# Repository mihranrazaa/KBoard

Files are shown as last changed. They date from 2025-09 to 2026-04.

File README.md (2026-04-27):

# KBoard

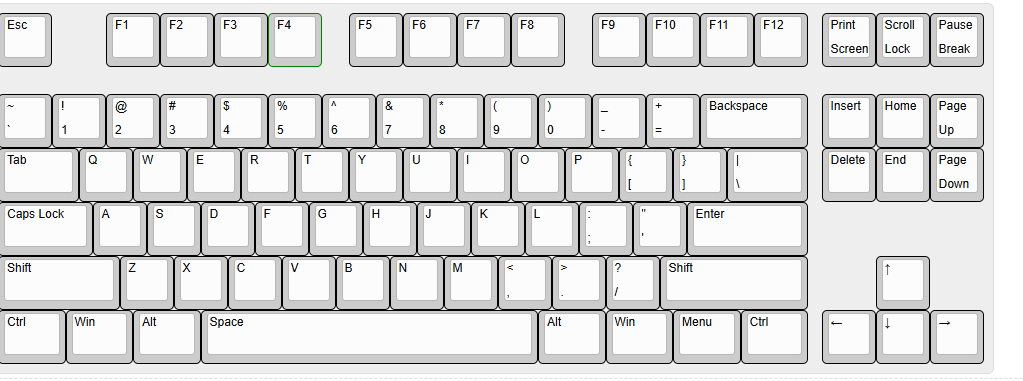
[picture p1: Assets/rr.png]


## Overview
a 75%% keyboard design, it is based on RP2040 plus with a type C port which came in-built with the MCU, there total of 87 MX switches with 5 Stabilizers. A complete keyboard :).

## Bit in depth info
The keyboard is designed to be sleek and plane it has RP2040 plus as the MCU and Cherry MX Brown Switches for the keys which are used for versatile purposes (that's what i saw at least). The main firmware is KMK based and the Firmware has already been released, you can find that in the Firmware and Production folder, I hate using different cables so having type c inbuilt in the RP2040 plus is a win-win.

---

## Files to build 

### PCB 

The files for the PCB and Schematics are available in the Kicad folder and gerber files are added in the Production folder..

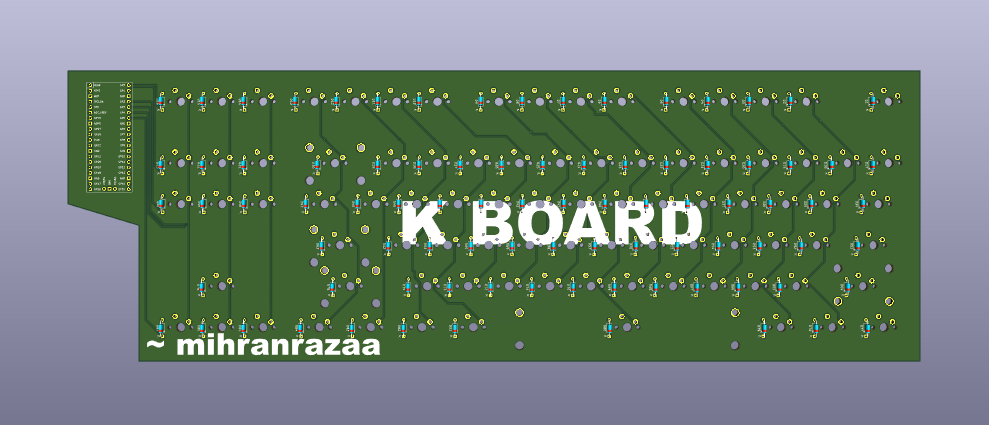
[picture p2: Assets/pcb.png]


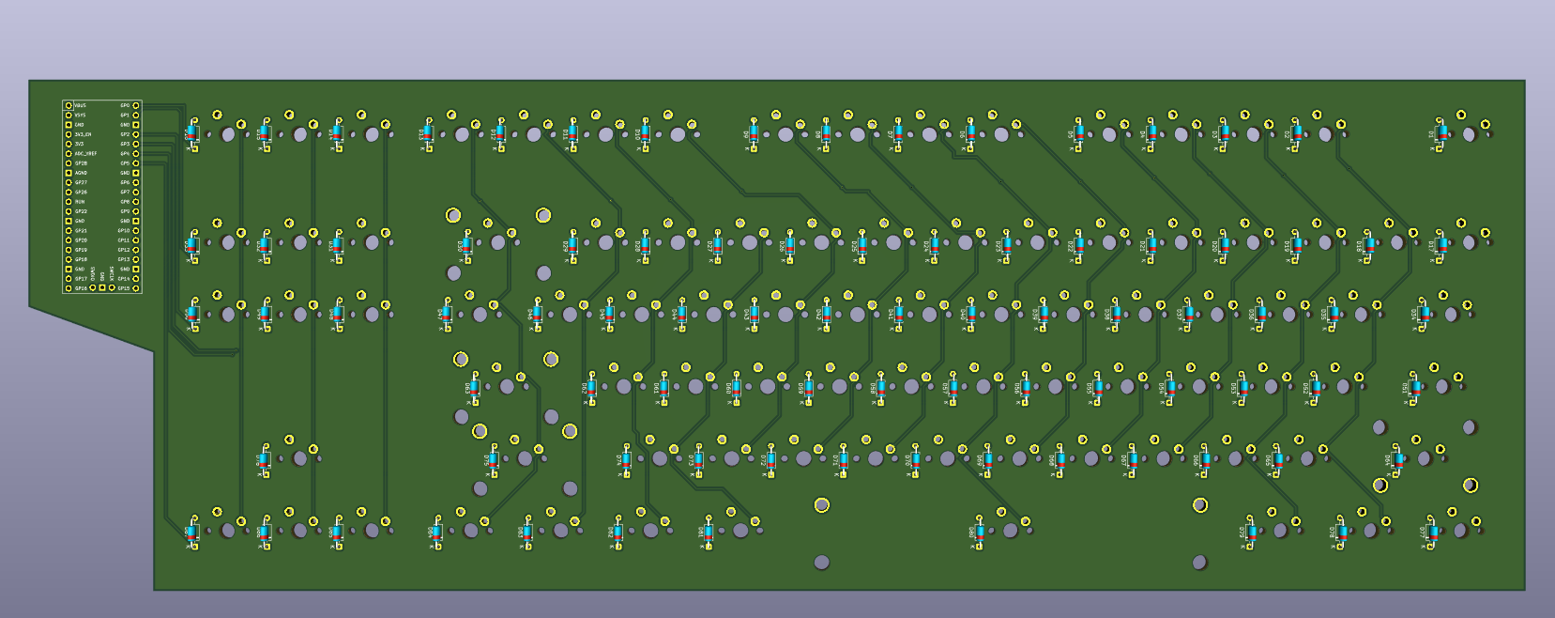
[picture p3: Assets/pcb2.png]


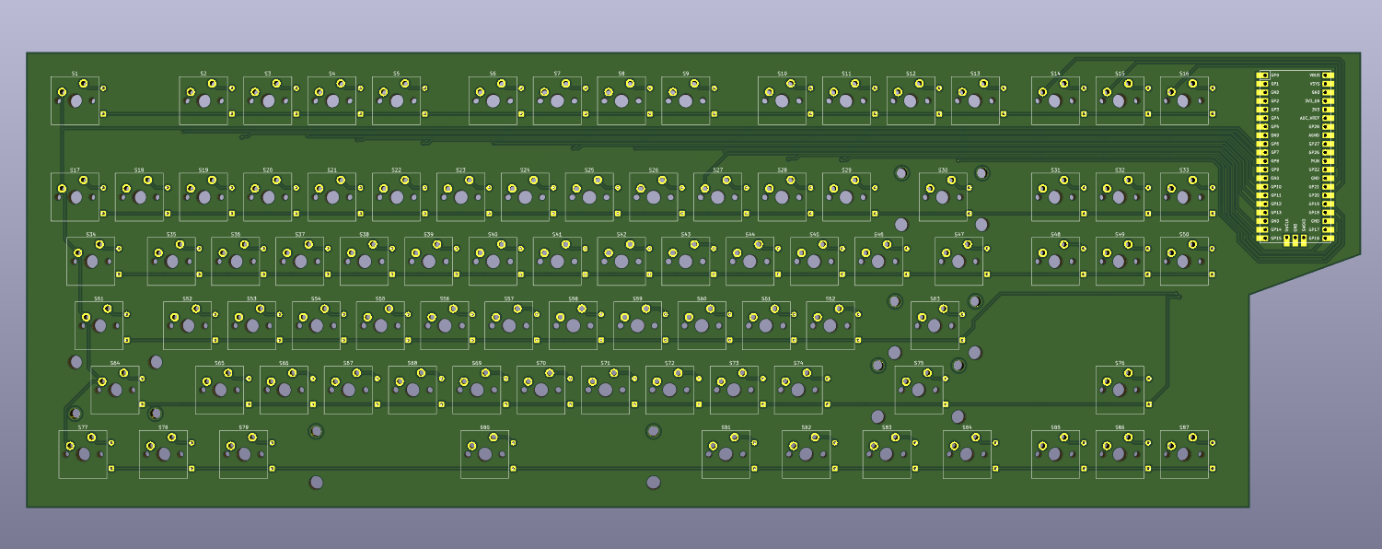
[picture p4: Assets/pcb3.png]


## Images

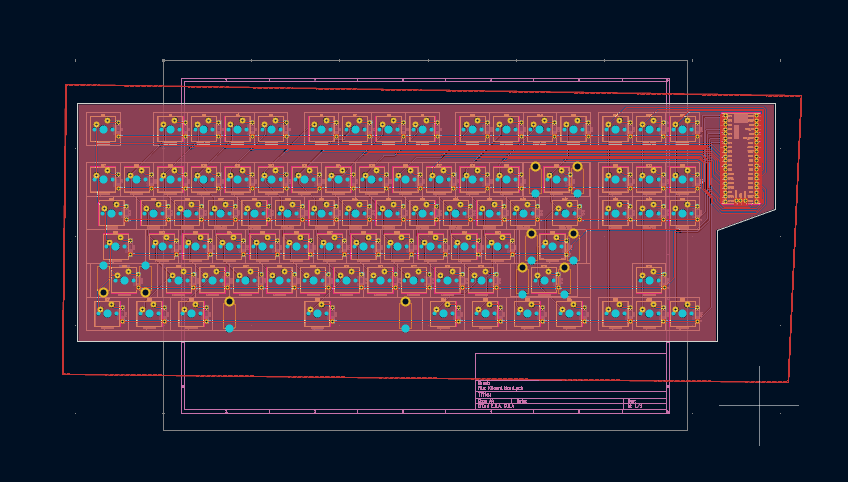
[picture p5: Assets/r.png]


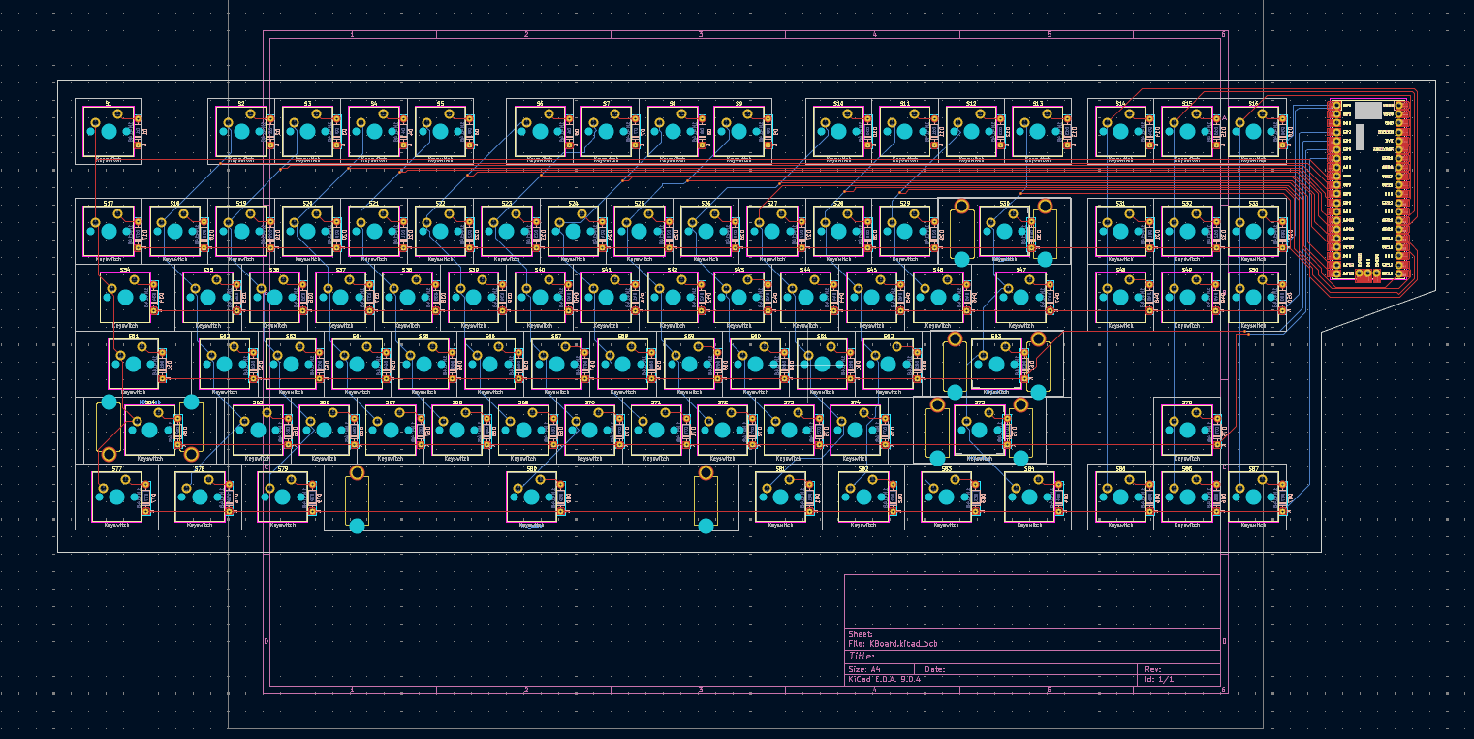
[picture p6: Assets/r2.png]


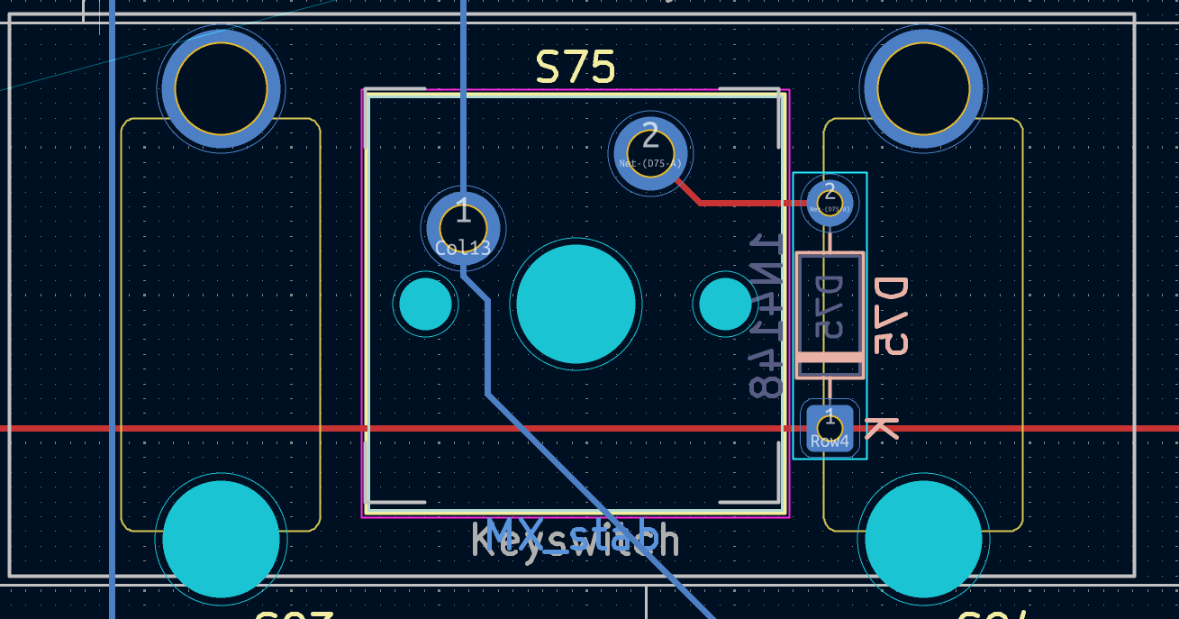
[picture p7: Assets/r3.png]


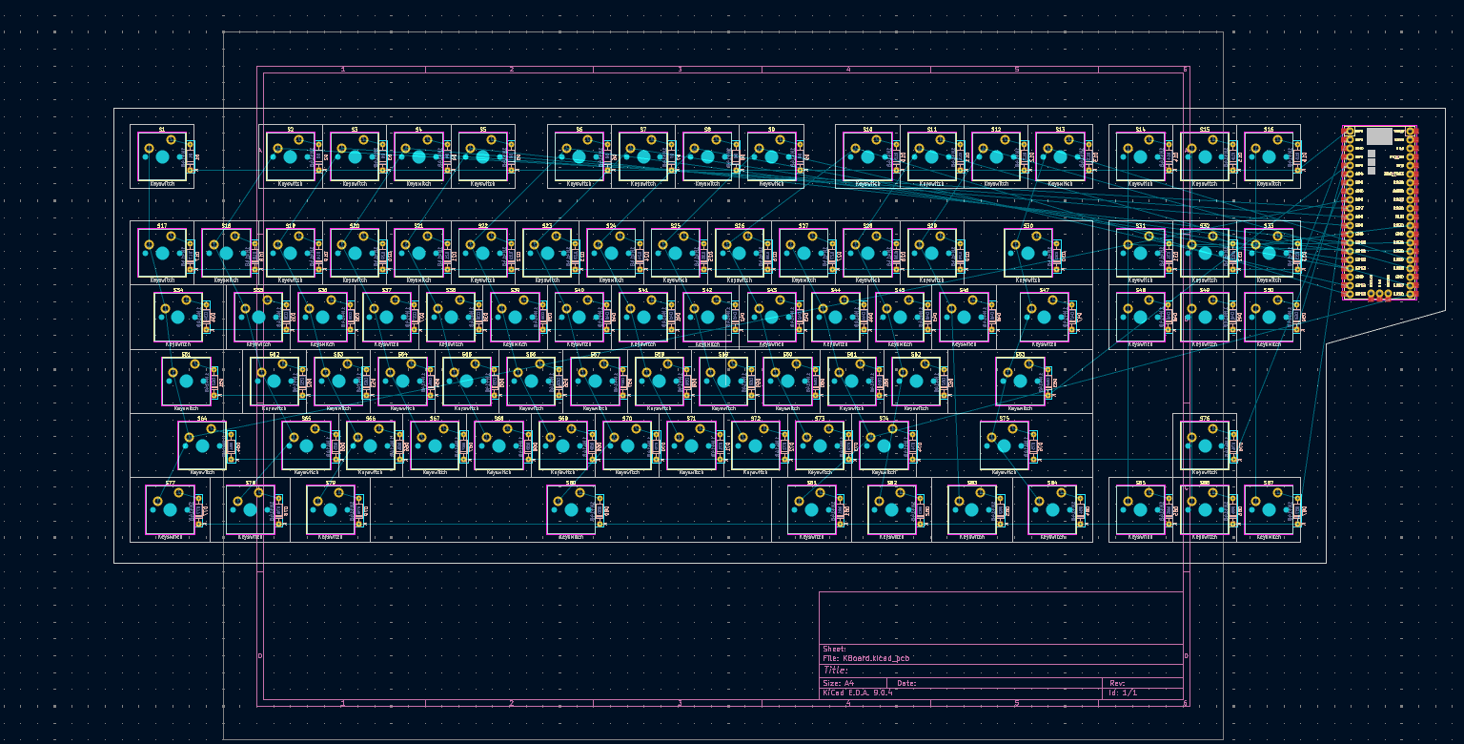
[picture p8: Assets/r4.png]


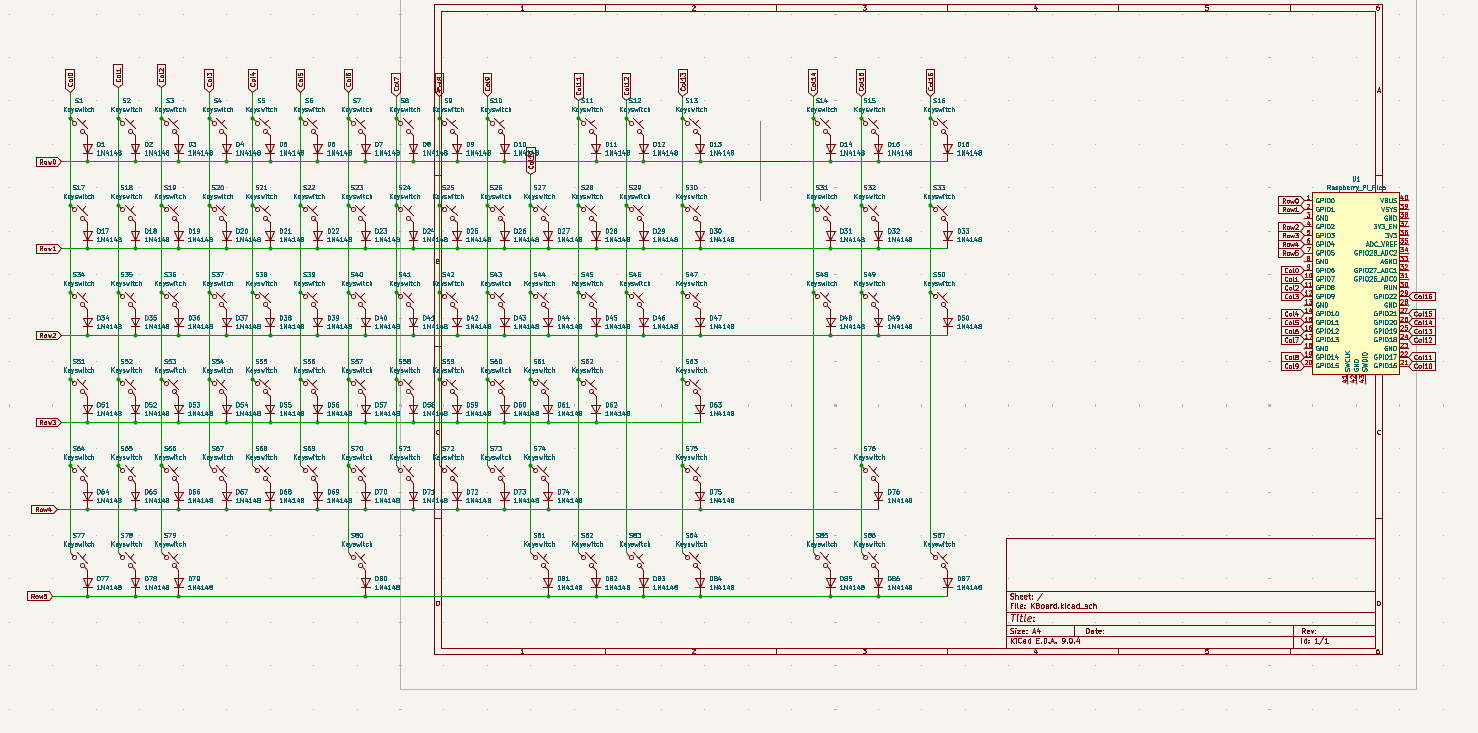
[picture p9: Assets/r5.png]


### Case 

The files for the case and plate are available in the CAD folder and in the Production folder..

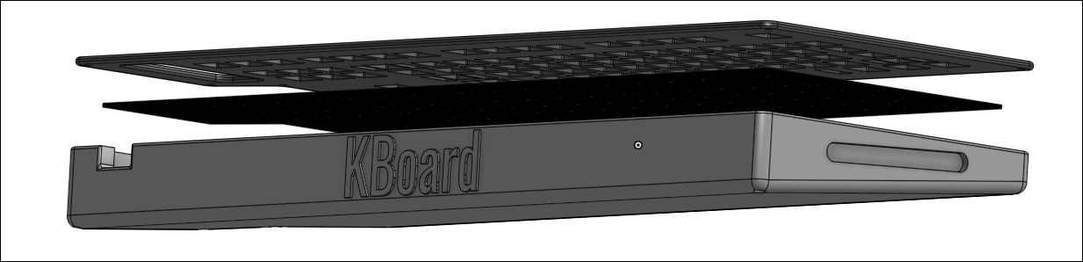
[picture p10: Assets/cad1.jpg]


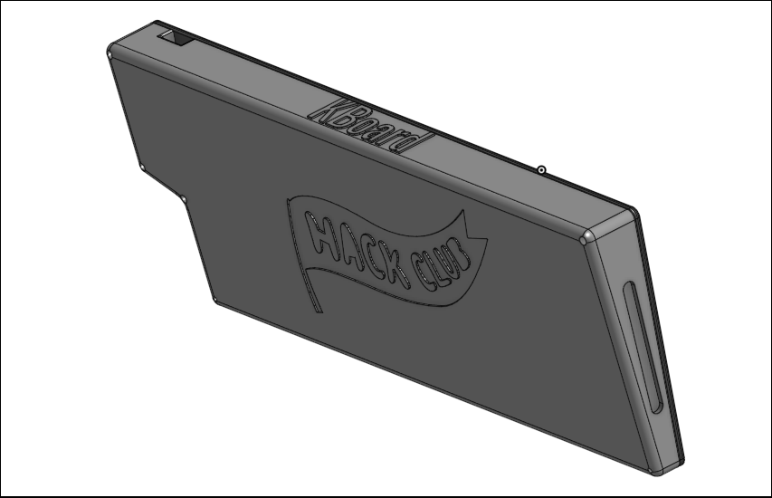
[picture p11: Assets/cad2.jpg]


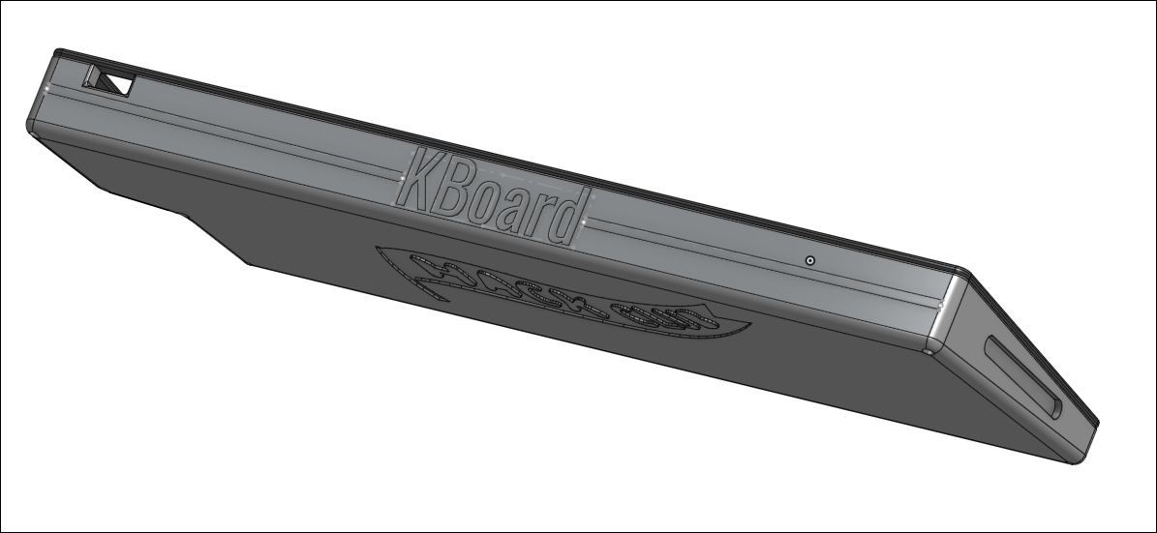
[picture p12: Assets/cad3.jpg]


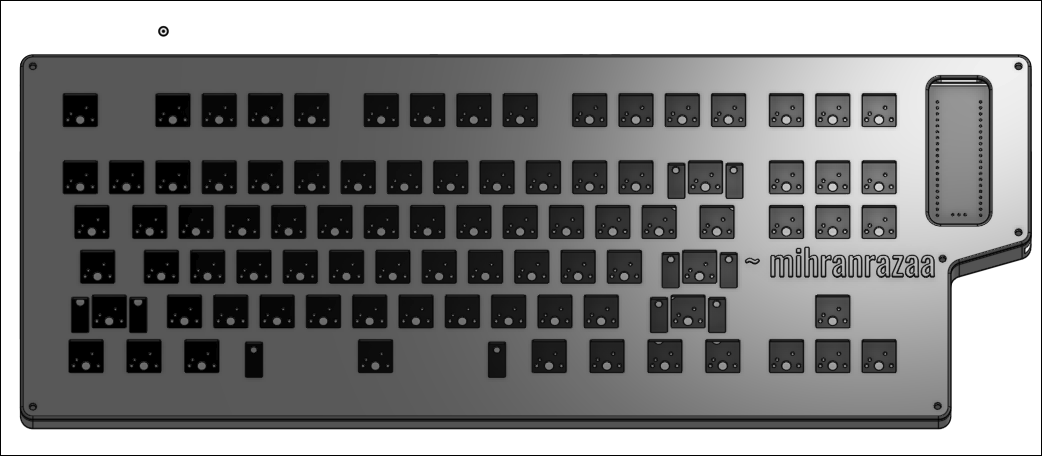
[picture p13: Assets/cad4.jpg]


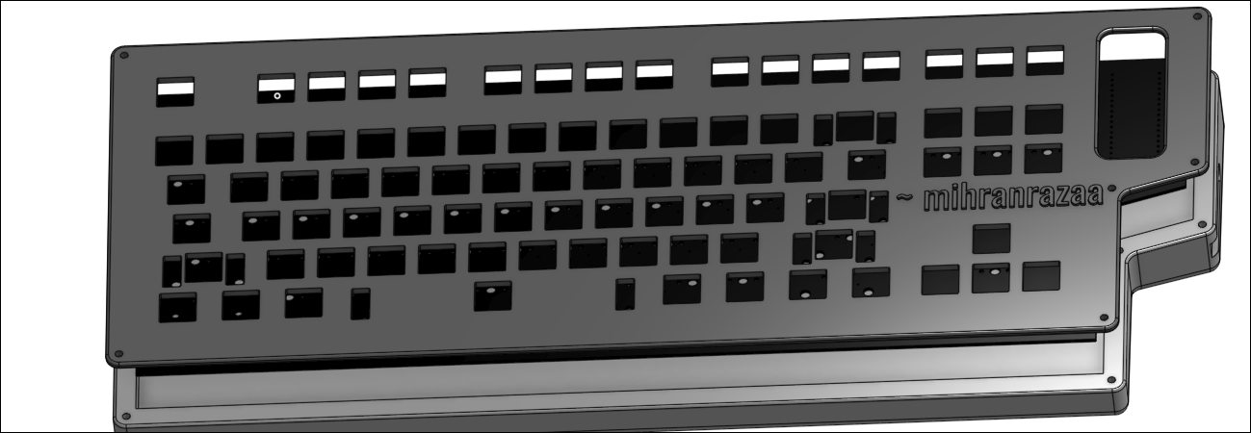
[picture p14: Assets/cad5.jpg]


---

---

## BOM

| Component | Quantity | Note | Price | Link |
| --- | --- | --- | --- | --- |
| Akko Yello creamy | 2 | Found a good website!! | 25USD | [Available](https://stackskb.com/store/akko-v5-creamy-yellow-pro-switch-pack-of-45/) |
| Grey Keycaps set | 1 | Good Asthetics are important I will keep the body grey :) | 16USD | [Available](https://stackskb.com/store/white-grey-and-yellow-double-shot-abs-cherry-profile-keycaps/) |
| Stabilizer set | 1 | PCB Mounted Stabs| 17USD | [Available](https://stackskb.com/store/durock-smokey-screw-in-stabilizers-v2/) |
| Case & PCB | 1 | This is the cheapest i could find | 63USD | https://robu.in/ |
| TOTAL | | | 110-120 | |

---

made with <3 by [mihranrazaa](https://mihranrazaa.info/)

BYEEE

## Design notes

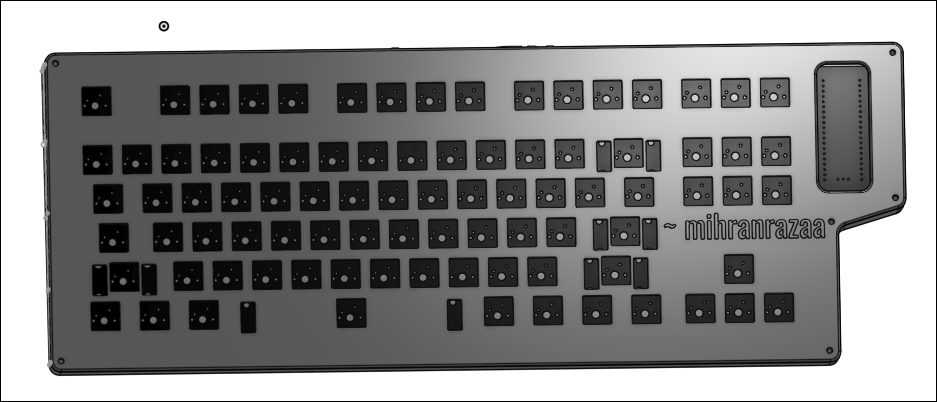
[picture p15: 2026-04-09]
Assets/screenshot_20260409_134501.jpg

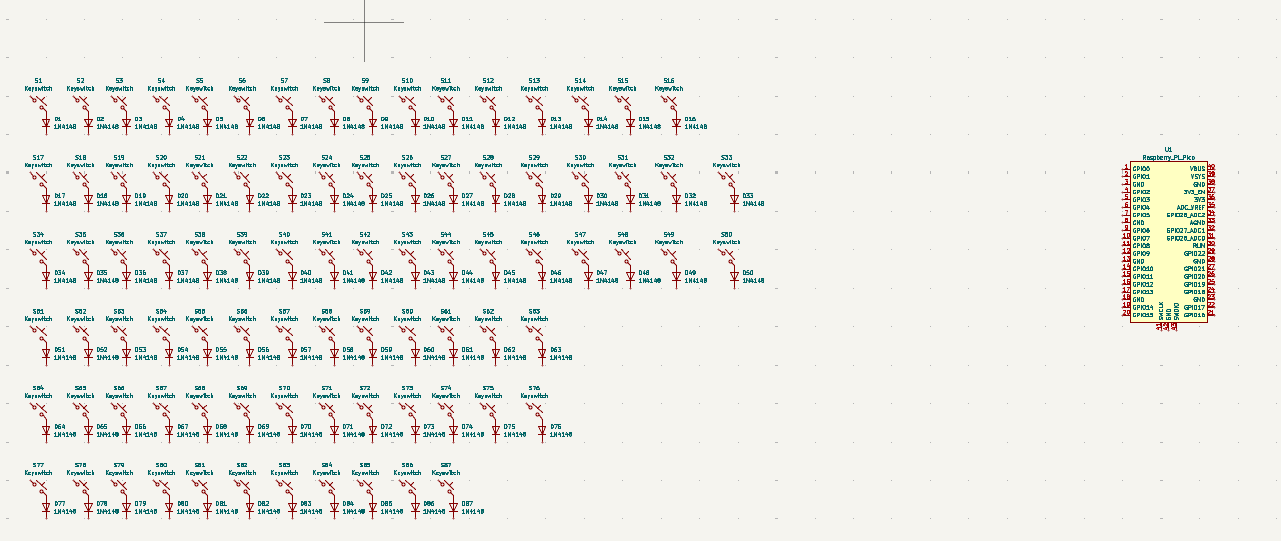
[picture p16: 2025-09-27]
Assets/Screenshot 2025-09-27 145318.png

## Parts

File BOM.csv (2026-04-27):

Name | Quantity | Price(USD) | Links | Notes(if any)
Akko Yello creamy | 2 | 25 | https://stackskb.com/store/akko-v5-creamy-yellow-pro-switch-pack-of-45/
Keycaps | 1 | 16 | https://stackskb.com/store/white-grey-and-yellow-double-shot-abs-cherry-profile-keycaps/
Stabilizer set | 1 | 17 | https://stackskb.com/store/durock-smokey-screw-in-stabilizers-v2/
Rotary Encoder (no need) | 1 | 1.5 | https://www.amazon.in/KitsGuru-Rotary-Decoder-Encoder-Module/dp/B01HHRJXS8
Case & PCB |  | 63 | https://robu.in/
Diodes (no need) | 87 | 4-5 | https://www.amazon.in/Circuit-Ranger-Switching-Electronic-Projects/dp/B0FJLP12GX
RP2040 MCU | 1 | 6 | https://www.fabtolab.com/waveshare-rp2040-plus-pico-like-mcu-board-raspberry-pi-usb-c

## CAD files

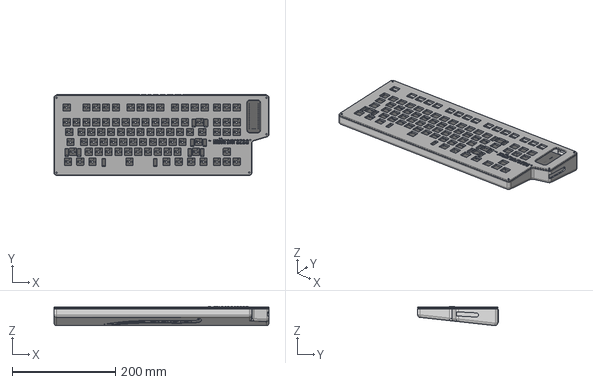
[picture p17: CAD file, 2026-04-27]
CAD/KBoard-Complete-assembly-with-pcb.step
415.5 x 156.0 x 37.4 mm

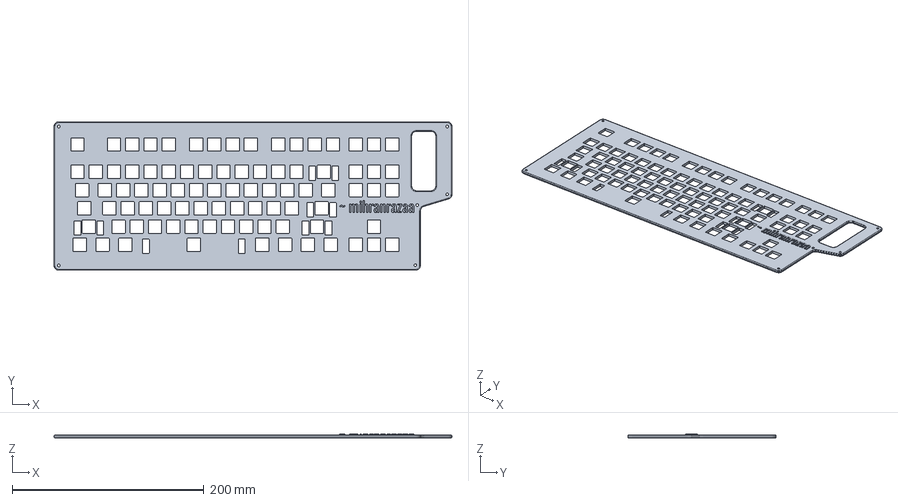
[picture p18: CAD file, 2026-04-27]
CAD/KBoard - Plate-case.step
415.5 x 155.0 x 4.00 mm

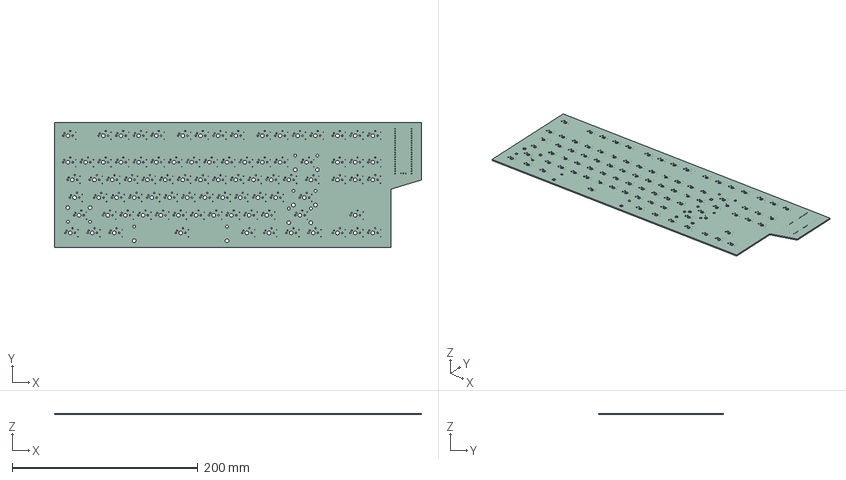
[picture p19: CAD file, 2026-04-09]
KICAD/KBoard.step
395.5 x 135.0 x 1.51 mm

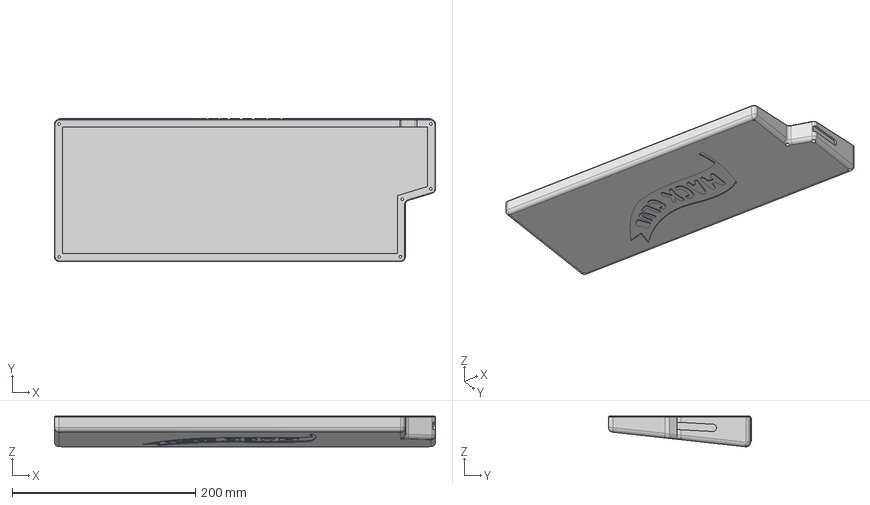
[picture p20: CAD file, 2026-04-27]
CAD/KBoard - Base-case.step
415.5 x 156.0 x 33.4 mm

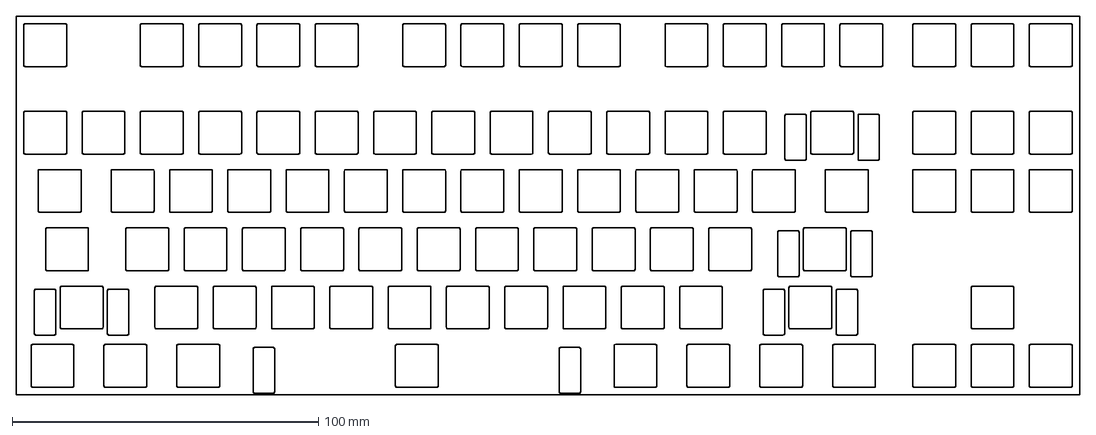
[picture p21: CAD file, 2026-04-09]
CAD/plate.dxf
347.7 x 123.8 mm

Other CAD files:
CAD/KBoard - Base-case.3mf
CAD/KBoard - Plate-case.3mf
Production/KBoard - Base-case.3mf
Production/KBoard - Plate-case.3mf

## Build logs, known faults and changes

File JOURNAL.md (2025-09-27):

<!--
  ===================    !!READ THIS NOTICE!!   ====================
  DO NOT edit this file manually. Your changes WILL BE OVERWRITTEN!
  This journal is auto generated and updated by Hack Club Blueprint.
  To edit this file, please edit your journal entries on Blueprint.
  ==================================================================
-->

This is my journal of the design and building process of **KBoard**.  
You can view this journal in more detail on **Hack Club Blueprint** [here](https://blueprint.hackclub.com/projects/19).

## 9/26/2025 - Finalized components  

I already have almost all the required components + i want to use all my idle components, i will using RP2040 Plus devboard by Waveshare as MCU, Cherry MX brown switches, and 1N4148 Diodes, and PCB mount stabs and rotary encoder 2-3 depends if i find some use of the third one..

WhatsApp Image 2025-09-26 at 9.04.16 PM.jpeg  

## 9/27/2025 9 AM - Basic Schematic is done  

Downloaded all the libs as i just installed and setup another OS, i haven't added rotary encoders i will replace them with top-right last 3 switches or maybe not :\ , need to connect, i will do that after a break + i'm also thinking of adding a oled display because  also have a spare oled display so maybe i will use that too...

Screenshot 2025-09-27 145318.png

Screenshot 2025-09-27 144712.png

## 9/27/2025 10 AM - Completed Schematics!   

Schematics is doneeeeeeeeeee! 
I have dropped the idea of using rotary encoder as i can't find a good use tho i thought of using them as brightness and volume control but i already have a macropad for that so it would be useless... 
And now i will complete this kboard todayyyyy!!

Screenshot 2025-09-27 160321.png

## 9/27/2025 6 PM - Routed the PCB!  

My Keyboard PCB is done!!
i have routed the pcb, added no net fill, added stabilizers and mostly is completed now i want to add some art on it, then seting up the readme and github page and most work will be done, i put the mcu in the corner which looks good imo, i had some errors on DRC but i fixed them pretty easily..... 
i had some things to write but now i forgot at the end because i took a break between writing this and completing the pcb :/. But this were the major happenings and thoughts. 

--- 

Here are all the images from this session. BYEE ::

Screenshot 2025-09-27 215656.png
Screenshot 2025-09-27 211109.png
Screenshot 2025-09-27 215710.png
Screenshot 2025-09-27 215507.png
Screenshot 2025-09-27 164509.png
Screenshot 2025-09-27 202722.png

## 9/27/2025 9 PM - Shipping time!!!  

Alright i have done everything for the version which is ready fr shipping, i didn't add art as it would have been covered under the switches anyways.. so i added the name of keeb in the back, next i updated my github with the proper readme and added all the files, i have added bom in the root and production directory also added links in the readme, i think it is pretty much ready to ship yeah!!!!

---

Here is the final image of the pcb::

Screenshot 2025-09-28 021334.png
Screenshot 2025-09-27 215656.png

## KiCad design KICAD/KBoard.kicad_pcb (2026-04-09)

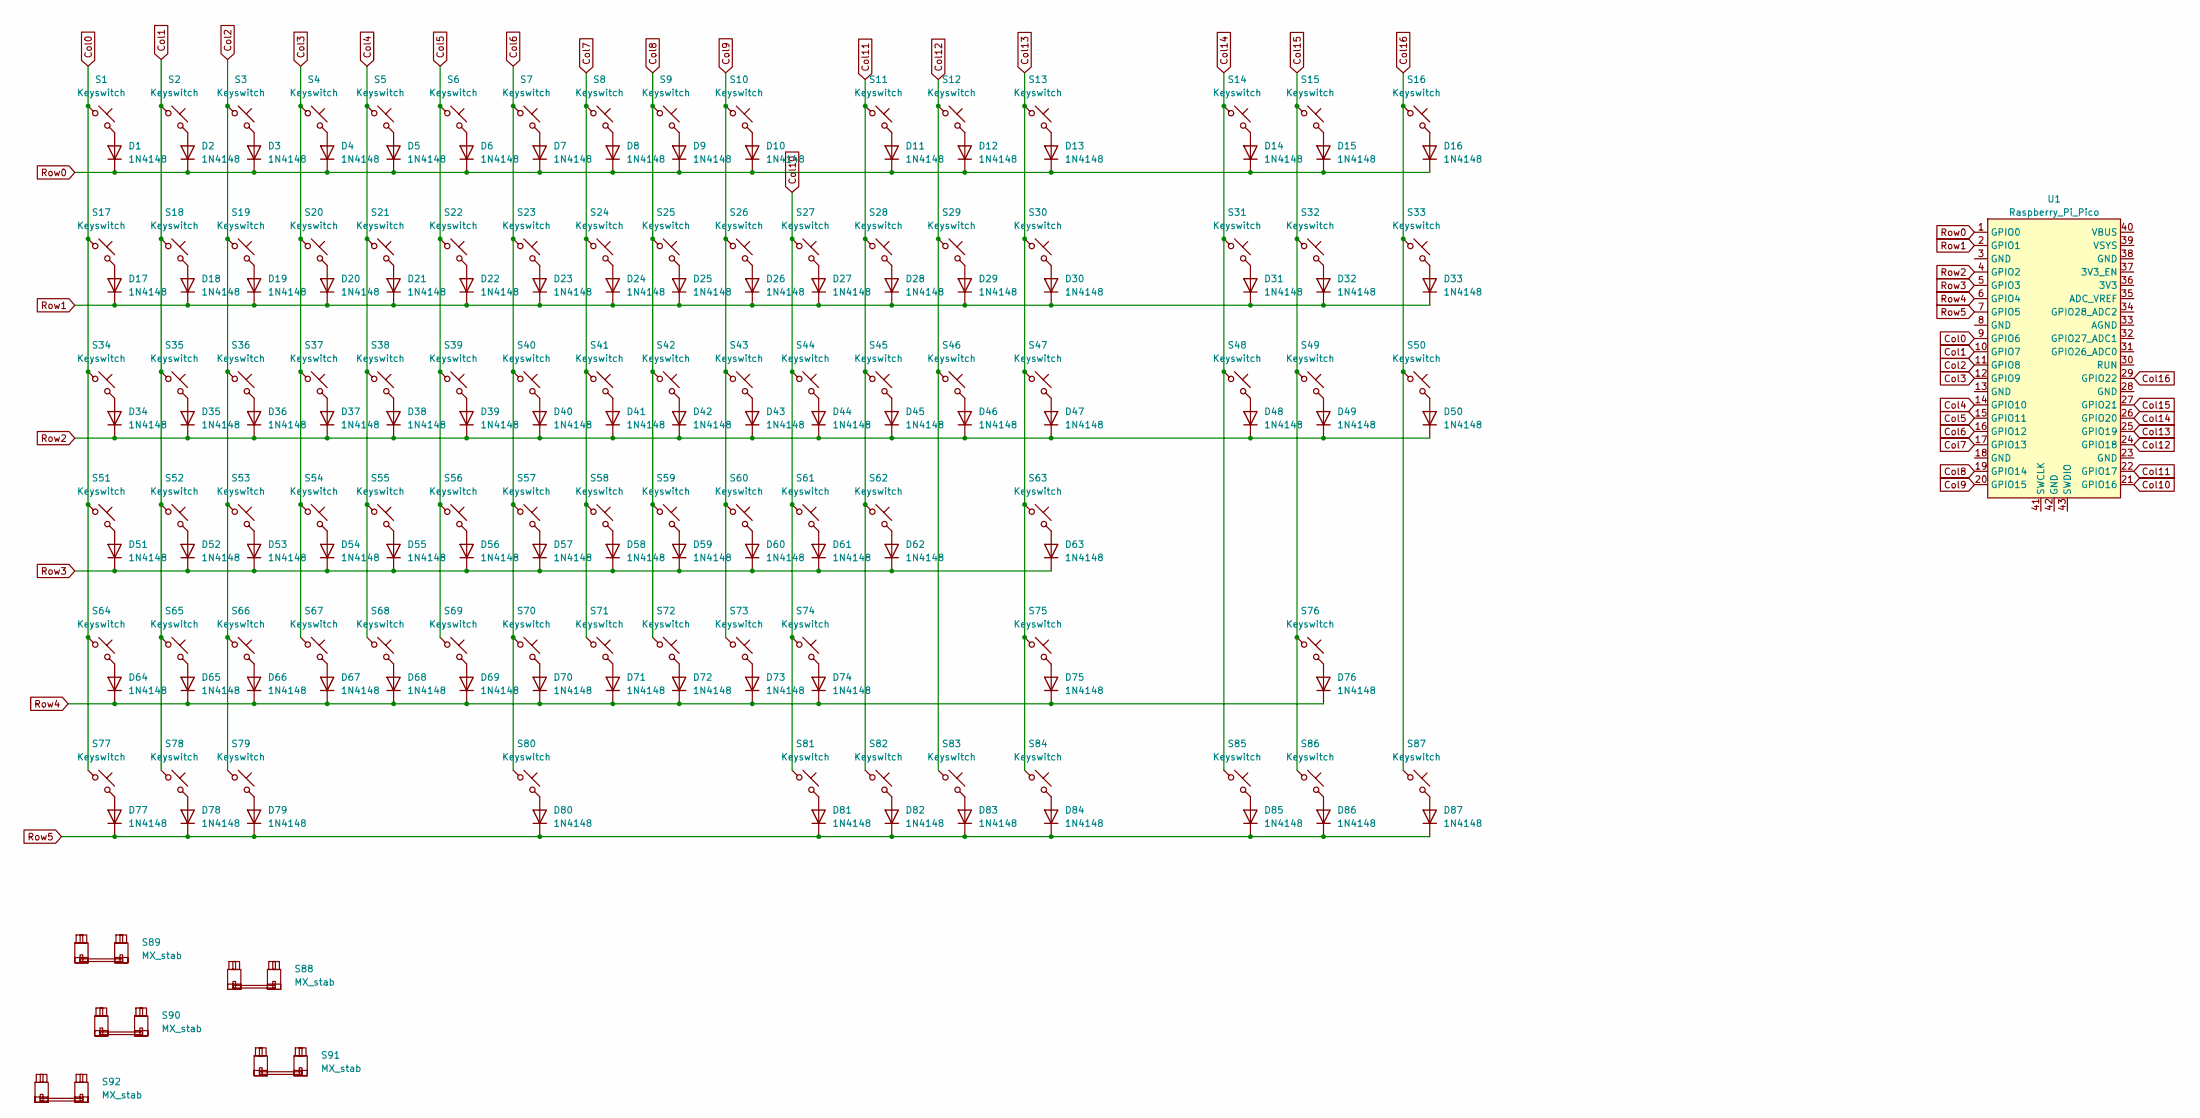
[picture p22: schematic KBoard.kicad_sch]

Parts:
D1, D2, D3, D4, D5, D6, D7, D8, D9, D10, D11, D12, D13, D14, D15, D16, D17, D18, D19, D20, D21, D22, D23, D24, D25, D26, D27, D28, D29, D30, D31, D32, D33, D34, D35, D36, D37, D38, D39, D40, D41, D42, D43, D44, D45, D46, D47, D48, D49, D50, D51, D52, D53, D54, D55, D56, D57, D58, D59, D60, D61, D62, D63, D64, D65, D66, D67, D68, D69, D70, D71, D72, D73, D74, D75, D76, D77, D78, D79, D80, D81, D82, D83, D84, D85, D86, D87: 1N4148; D_DO-35_SOD27_P7.62mm_Horizontal
S1, S2, S3, S4, S5, S6, S7, S8, S9, S10, S11, S12, S13, S14, S15, S16, S17, S18, S19, S20, S21, S22, S23, S24, S25, S26, S27, S28, S29, S31, S32, S33, S35, S36, S37, S38, S39, S40, S41, S42, S43, S44, S45, S46, S48, S49, S50, S52, S53, S54, S55, S56, S57, S58, S59, S60, S61, S62, S65, S66, S67, S68, S69, S70, S71, S72, S73, S74, S76, S85, S86, S87: Keyswitch; MX_PCB_1.00u
S30: Keyswitch; MX_PCB_2.00u
S34, S47: Keyswitch; MX_PCB_1.50u
S51: Keyswitch; MX_PCB_1.75u
S63, S64: Keyswitch; MX_PCB_2.25u
S75: Keyswitch; MX_PCB_2.75u
S77, S78, S79, S81, S82, S83, S84: Keyswitch; MX_PCB_1.25u
S80: Keyswitch; MX_PCB_6.25u
S88: MX_stab; STAB_MX_P_6.25u
S89, S90, S91, S92: MX_stab; STAB_MX_P_2u
U1: Raspberry_Pi_Pico

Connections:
Col0: S1.1, S17.1, S34.1, S51.1, S64.1, S77.1, U1.9 (GPIO6)
Col1: S2.1, S18.1, S35.1, S52.1, S65.1, S78.1, U1.10 (GPIO7)
Col2: S3.1, S19.1, S36.1, S53.1, S66.1, S79.1, U1.11 (GPIO8)
Col3: S4.1, S20.1, S37.1, S54.1, S67.1, U1.12 (GPIO9)
Col4: S5.1, S21.1, S38.1, S55.1, S68.1, U1.14 (GPIO10)
Col5: S6.1, S22.1, S39.1, S56.1, S69.1, U1.15 (GPIO11)
Col6: S7.1, S23.1, S40.1, S57.1, S70.1, S80.1, U1.16 (GPIO12)
Col7: S8.1, S24.1, S41.1, S58.1, S71.1, U1.17 (GPIO13)
Col8: S9.1, S25.1, S42.1, S59.1, S72.1, U1.19 (GPIO14)
Col9: S10.1, S26.1, S43.1, S60.1, S73.1, U1.20 (GPIO15)
Col10: S27.1, S44.1, S61.1, S74.1, S81.1, U1.21 (GPIO16)
Col11: S11.1, S28.1, S45.1, S62.1, S82.1, U1.22 (GPIO17)
Col12: S12.1, S29.1, S46.1, S83.1, U1.24 (GPIO18)
Col13: S13.1, S30.1, S47.1, S63.1, S75.1, S84.1, U1.25 (GPIO19)
Col14: S14.1, S31.1, S48.1, S85.1, U1.26 (GPIO20)
Col15: S15.1, S32.1, S49.1, S76.1, S86.1, U1.27 (GPIO21)
Col16: S16.1, S33.1, S50.1, S87.1, U1.29 (GPIO22)
unnamed: D1.2 (A), S1.2
unnamed: D2.2 (A), S2.2
unnamed: D3.2 (A), S3.2
unnamed: D4.2 (A), S4.2
unnamed: D5.2 (A), S5.2
unnamed: D6.2 (A), S6.2
unnamed: D7.2 (A), S7.2
unnamed: D8.2 (A), S8.2
unnamed: D9.2 (A), S9.2
unnamed: D10.2 (A), S10.2
unnamed: D11.2 (A), S11.2
unnamed: D12.2 (A), S12.2
unnamed: D13.2 (A), S13.2
unnamed: D14.2 (A), S14.2
unnamed: D15.2 (A), S15.2
unnamed: D16.2 (A), S16.2
unnamed: D17.2 (A), S17.2
unnamed: D18.2 (A), S18.2
unnamed: D19.2 (A), S19.2
unnamed: D20.2 (A), S20.2
unnamed: D21.2 (A), S21.2
unnamed: D22.2 (A), S22.2
unnamed: D23.2 (A), S23.2
unnamed: D24.2 (A), S24.2
unnamed: D25.2 (A), S25.2
unnamed: D26.2 (A), S26.2
unnamed: D27.2 (A), S27.2
unnamed: D28.2 (A), S28.2
unnamed: D29.2 (A), S29.2
unnamed: D30.2 (A), S30.2
unnamed: D31.2 (A), S31.2
unnamed: D32.2 (A), S32.2
unnamed: D33.2 (A), S33.2
unnamed: D34.2 (A), S34.2
unnamed: D35.2 (A), S35.2
unnamed: D36.2 (A), S36.2
unnamed: D37.2 (A), S37.2
unnamed: D38.2 (A), S38.2
unnamed: D39.2 (A), S39.2
unnamed: D40.2 (A), S40.2
unnamed: D41.2 (A), S41.2
unnamed: D42.2 (A), S42.2
unnamed: D43.2 (A), S43.2
unnamed: D44.2 (A), S44.2
unnamed: D45.2 (A), S45.2
unnamed: D46.2 (A), S46.2
unnamed: D47.2 (A), S47.2
unnamed: D48.2 (A), S48.2
unnamed: D49.2 (A), S49.2
unnamed: D50.2 (A), S50.2
unnamed: D51.2 (A), S51.2
unnamed: D52.2 (A), S52.2
unnamed: D53.2 (A), S53.2
unnamed: D54.2 (A), S54.2
unnamed: D55.2 (A), S55.2
unnamed: D56.2 (A), S56.2
unnamed: D57.2 (A), S57.2
unnamed: D58.2 (A), S58.2
unnamed: D59.2 (A), S59.2
unnamed: D60.2 (A), S60.2
unnamed: D61.2 (A), S61.2
unnamed: D62.2 (A), S62.2
unnamed: D63.2 (A), S63.2
unnamed: D64.2 (A), S64.2
unnamed: D65.2 (A), S65.2
unnamed: D66.2 (A), S66.2
unnamed: D67.2 (A), S67.2
unnamed: D68.2 (A), S68.2
unnamed: D69.2 (A), S69.2
unnamed: D70.2 (A), S70.2
unnamed: D71.2 (A), S71.2
unnamed: D72.2 (A), S72.2
unnamed: D73.2 (A), S73.2
unnamed: D74.2 (A), S74.2
unnamed: D75.2 (A), S75.2
unnamed: D76.2 (A), S76.2
unnamed: D77.2 (A), S77.2
unnamed: D78.2 (A), S78.2
unnamed: D79.2 (A), S79.2
unnamed: D80.2 (A), S80.2
unnamed: D81.2 (A), S81.2
unnamed: D82.2 (A), S82.2
unnamed: D83.2 (A), S83.2
unnamed: D84.2 (A), S84.2
unnamed: D85.2 (A), S85.2
unnamed: D86.2 (A), S86.2
unnamed: D87.2 (A), S87.2
Row0: D1.1 (K), D2.1 (K), D3.1 (K), D4.1 (K), D5.1 (K), D6.1 (K), D7.1 (K), D8.1 (K), D9.1 (K), D10.1 (K), D11.1 (K), D12.1 (K), D13.1 (K), D14.1 (K), D15.1 (K), D16.1 (K), U1.1 (GPIO0)
Row1: D17.1 (K), D18.1 (K), D19.1 (K), D20.1 (K), D21.1 (K), D22.1 (K), D23.1 (K), D24.1 (K), D25.1 (K), D26.1 (K), D27.1 (K), D28.1 (K), D29.1 (K), D30.1 (K), D31.1 (K), D32.1 (K), D33.1 (K), U1.2 (GPIO1)
Row2: D34.1 (K), D35.1 (K), D36.1 (K), D37.1 (K), D38.1 (K), D39.1 (K), D40.1 (K), D41.1 (K), D42.1 (K), D43.1 (K), D44.1 (K), D45.1 (K), D46.1 (K), D47.1 (K), D48.1 (K), D49.1 (K), D50.1 (K), U1.4 (GPIO2)
Row3: D51.1 (K), D52.1 (K), D53.1 (K), D54.1 (K), D55.1 (K), D56.1 (K), D57.1 (K), D58.1 (K), D59.1 (K), D60.1 (K), D61.1 (K), D62.1 (K), D63.1 (K), U1.5 (GPIO3)
Row4: D64.1 (K), D65.1 (K), D66.1 (K), D67.1 (K), D68.1 (K), D69.1 (K), D70.1 (K), D71.1 (K), D72.1 (K), D73.1 (K), D74.1 (K), D75.1 (K), D76.1 (K), U1.6 (GPIO4)
Row5: D77.1 (K), D78.1 (K), D79.1 (K), D80.1 (K), D81.1 (K), D82.1 (K), D83.1 (K), D84.1 (K), D85.1 (K), D86.1 (K), D87.1 (K), U1.7 (GPIO5)

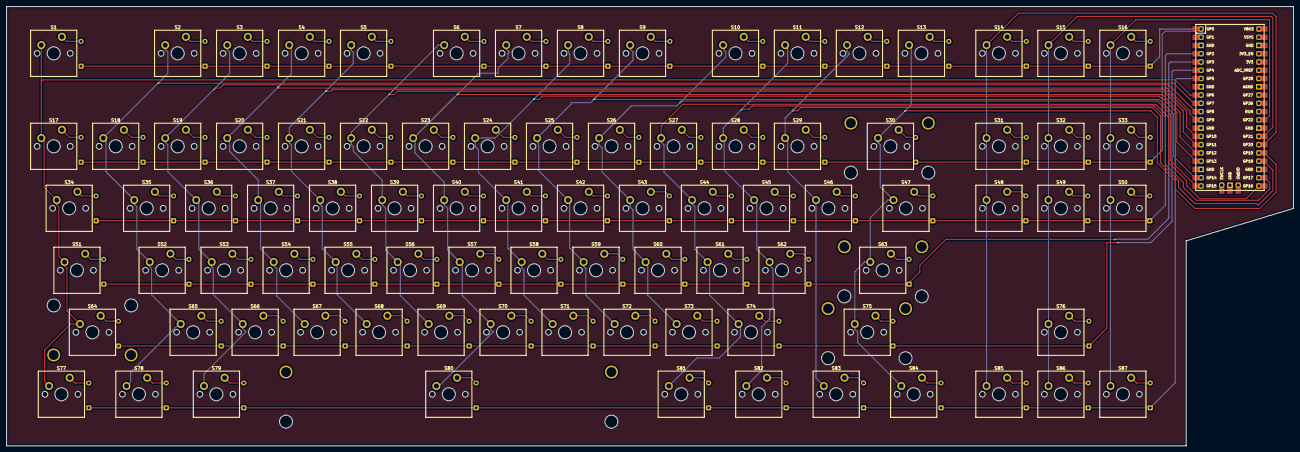
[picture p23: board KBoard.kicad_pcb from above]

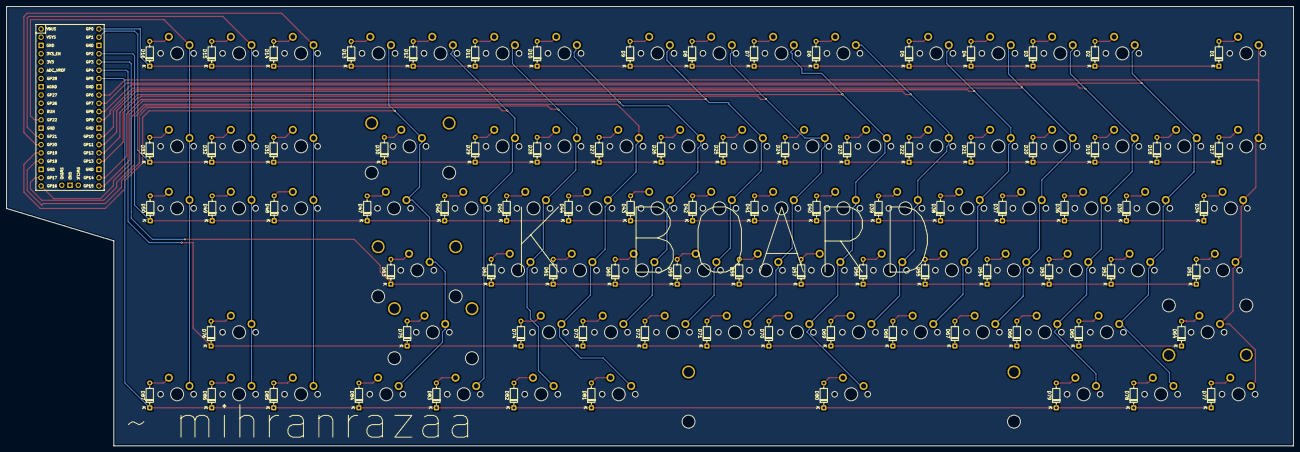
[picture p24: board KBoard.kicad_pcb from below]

Board: 2 copper layers, 395.5 x 135.0 mm, 180 parts (87 on the bottom side), 110 nets.

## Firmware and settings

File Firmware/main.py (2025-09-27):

import board
from kmk.kmk_keyboard import KMKKeyboard
from kmk.keys import KC
from kmk.matrix import DiodeOrientation
from kmk.modules.layers import Layers
from kmk.extensions.media_keys import MediaKeys
from kmk.modules.modtap import ModTap

keyboard = KMKKeyboard()

keyboard.modules.append(Layers())
keyboard.modules.append(ModTap())
keyboard.extensions.append(MediaKeys())


keyboard.row_pins = (
    board.GP0,   # Row 0
    board.GP1,   # Row 1  
    board.GP2,   # Row 2
    board.GP3,   # Row 3
    board.GP4,   # Row 4
    board.GP5,   # Row 5
)

keyboard.col_pins = (
    board.GP6,   # Col 0
    board.GP7,   # Col 1
    board.GP8,   # Col 2
    board.GP9,   # Col 3
    board.GP10,  # Col 4
    board.GP11,  # Col 5
    board.GP12,  # Col 6
    board.GP13,  # Col 7
    board.GP14,  # Col 8
    board.GP15,  # Col 9
    board.GP16,  # Col 10
    board.GP17,  # Col 11
    board.GP18,  # Col 12
    board.GP19,  # Col 13
    board.GP20,  # Col 14
    board.GP21,  # Col 15
)

keyboard.diode_orientation = DiodeOrientation.COL2ROW



# layers
keyboard.keymap = [
    # Layer 0
    [
        KC.ESC,    KC.F1,   KC.F2,   KC.F3,   KC.F4,   KC.F5,   KC.F6,   KC.F7,   KC.F8,   KC.F9,   KC.F10,  KC.F11,  KC.F12,  KC.PSCR, KC.SLCK, KC.PAUS,
        KC.GRV,    KC.N1,   KC.N2,   KC.N3,   KC.N4,   KC.N5,   KC.N6,   KC.N7,   KC.N8,   KC.N9,   KC.N0,   KC.MINS, KC.EQL,  KC.BSPC,          KC.INS,  KC.HOME, KC.PGUP,
        KC.TAB,    KC.Q,    KC.W,    KC.E,    KC.R,    KC.T,    KC.Y,    KC.U,    KC.I,    KC.O,    KC.P,    KC.LBRC, KC.RBRC, KC.BSLS,          KC.DEL,  KC.END,  KC.PGDN,
        KC.CAPS,   KC.A,    KC.S,    KC.D,    KC.F,    KC.G,    KC.H,    KC.J,    KC.K,    KC.L,    KC.SCLN, KC.QUOT,          KC.ENT,
        KC.LSFT,   KC.Z,    KC.X,    KC.C,    KC.V,    KC.B,    KC.N,    KC.M,    KC.COMM, KC.DOT,  KC.SLSH,          KC.RSFT,                            KC.UP,
        KC.LCTL,   KC.LGUI, KC.LALT,                   KC.SPC,                            KC.RALT, KC.RGUI, KC.MENU, KC.RCTL,          KC.LEFT, KC.DOWN, KC.RGHT,
    ],
    
    # Layer 1
    [
        KC.TRNS,   KC.TRNS, KC.TRNS, KC.TRNS, KC.TRNS, KC.TRNS, KC.TRNS, KC.TRNS, KC.TRNS, KC.TRNS, KC.TRNS, KC.TRNS, KC.TRNS, KC.TRNS, KC.TRNS, KC.TRNS,
        KC.TRNS,   KC.TRNS, KC.TRNS, KC.TRNS, KC.TRNS, KC.TRNS, KC.TRNS, KC.TRNS, KC.TRNS, KC.TRNS, KC.TRNS, KC.TRNS, KC.TRNS, KC.TRNS,          KC.TRNS, KC.TRNS, KC.TRNS,
        KC.TRNS,   KC.TRNS, KC.TRNS, KC.TRNS, KC.TRNS, KC.TRNS, KC.TRNS, KC.TRNS, KC.TRNS, KC.TRNS, KC.TRNS, KC.TRNS, KC.TRNS, KC.TRNS,          KC.TRNS, KC.TRNS, KC.TRNS,
        KC.TRNS,   KC.TRNS, KC.TRNS, KC.TRNS, KC.TRNS, KC.TRNS, KC.TRNS, KC.TRNS, KC.TRNS, KC.TRNS, KC.TRNS, KC.TRNS,          KC.TRNS,
        KC.TRNS,   KC.TRNS, KC.TRNS, KC.TRNS, KC.TRNS, KC.TRNS, KC.TRNS, KC.TRNS, KC.TRNS, KC.TRNS, KC.TRNS,          KC.TRNS,                            KC.VOLU,
        KC.TRNS,   KC.TRNS, KC.TRNS,                   KC.TRNS,                            KC.TRNS, KC.TRNS, KC.TRNS, KC.TRNS,          KC.MPRV, KC.VOLD, KC.MNXT,
    ],
]

keyboard.debounce_time = 10

keyboard.tap_time = 200

if __name__ == '__main__':
    keyboard.go()

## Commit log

2025-09-27 Initial update
    [KBoard.kicad_pcb, KBoard.kicad_sch, bom.csv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]
2026-04-09 add case and update readme
    [KBoard - Base-case.3mf, KBoard - Plate-case.3mf, KBoard.kicad_pcb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]
2026-04-27 resolve issues
    [BOM.csv, KBoard - Base-case.step, KBoard - Plate-case.step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]
